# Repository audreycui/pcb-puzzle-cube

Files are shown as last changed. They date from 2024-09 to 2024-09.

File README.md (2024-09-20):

# pcb-puzzle-cube
Mechanical, Optical, &amp; Electronic Puzzle Cube

I made a puzzle cube for my wonderful electronics lab instructor who is also a professional trumpet player! A lot of the fun in making this was designing my circuits and mechanical components around 5 milled PCBs soldered together into a cube. Puzzles involve "playing" a sequence of notes on a flex PCB capacitive trumpet and using a butterfly flexure to align a laser path through a beamsplitter.

## Milled PCBs
From left to right, the sides of the cube include: 
1. WS2812b LEDs 
2. resistor combinations with pads for probing
3. laser diode regulated by a LM317 circuit and switched on/off electronically with a 2N7002 MOSFET 
4. QTPy ESP32 microcontroller
   
Sides 1 & 4 also include a photoresistor to detect laser beam alignment.

And the bottom:

5. 5V power jack, switches for the board power and laser power, mount for butterfly flexure
   


## Trumpet Capacitive Touch FlexPCB
I really wanted an excuse to fab a flexPCB, so I did so here. FlexPCB files are located in the <code>trumpet</code> subfolder. 

The connector end of the trumpet was designed to fit in a 6pin/1mm FPC connector. I ended up just soldering it directly to the board though, since I ended up finding an end mill small enough to carve out the 1mm pitch pads. It also helped me avoid buying an extra component. 



## Video Demo
Watch a video demo of the cube being solved [here](https://www.youtube.com/watch?v=AHTcb9tr4TA) :D

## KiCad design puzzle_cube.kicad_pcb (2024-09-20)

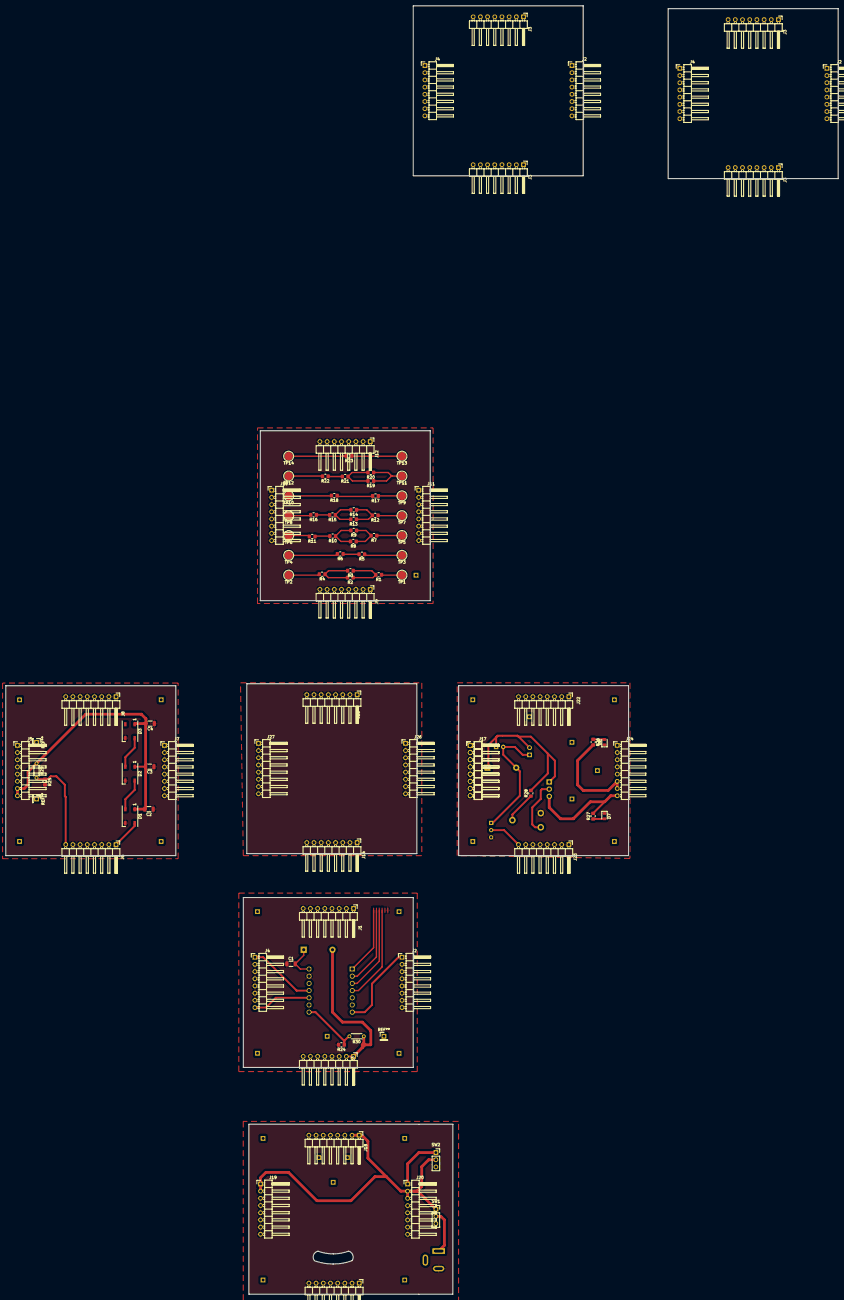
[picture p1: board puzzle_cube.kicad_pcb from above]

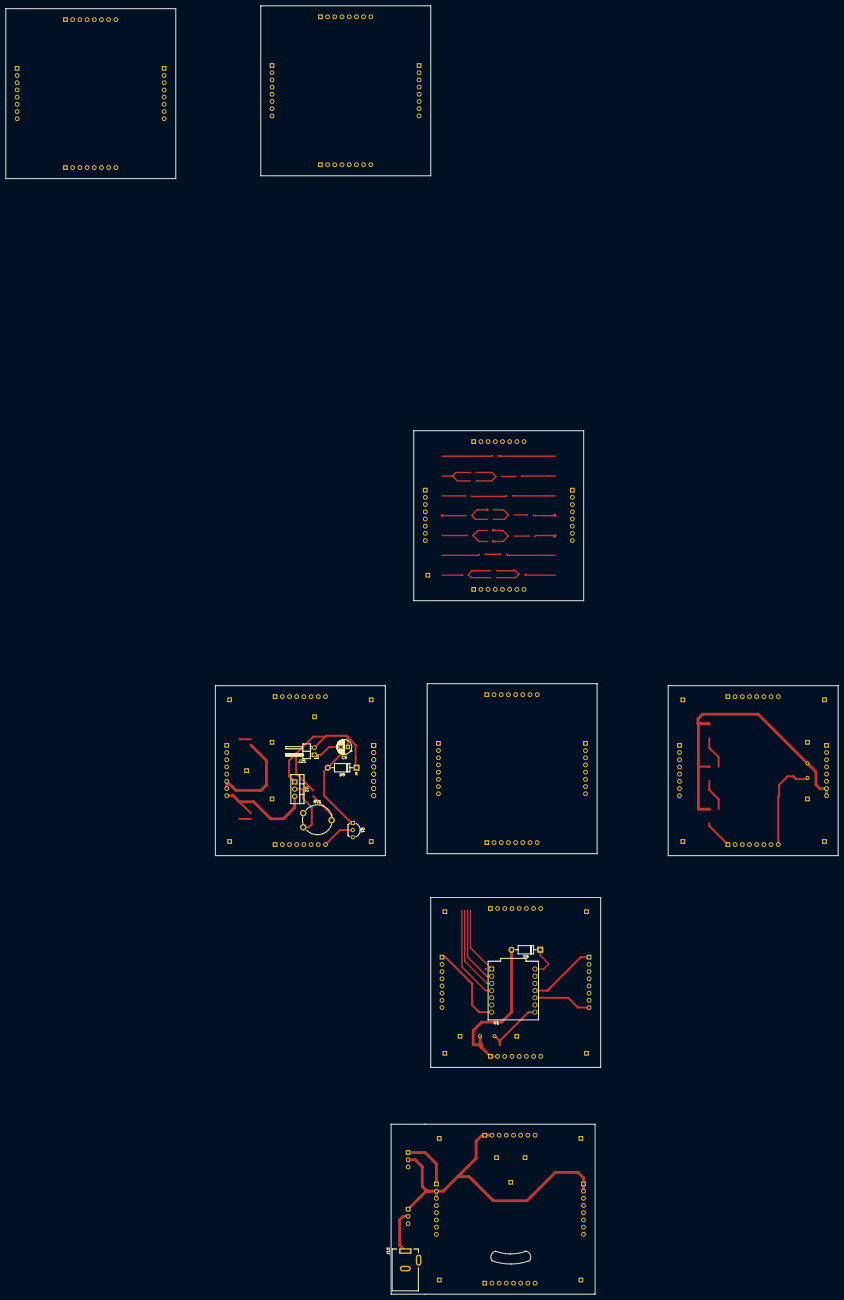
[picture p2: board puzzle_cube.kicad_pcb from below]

Board: 2 copper layers, 293.8 x 454.8 mm, 98 parts (9 on the bottom side), 47 nets.

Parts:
C1: C; C_1206_3216Metric
C2, C3, C4: 100uF; C_1206_3216Metric
C5: C; CP_Radial_D5.0mm_P2.50mm
D1, D2, D3: WS2812B; LED_WS2812B_PLCC4_5.0x5.0mm_P3.2mm
D6, D7: LED; LED_0805_2012Metric
D8, D9: 1N4007; D_DO-41_SOD81_P10.16mm_Horizontal
J1: qtpy2capacitive; PinHeader_1x08_P2.54mm_Horizontal
J2, J2#2, J3, J3#2, J3#4, J3#5, J4, J4#3: Conn_01x08_Pin; PinHeader_1x08_P2.54mm_Horizontal
J2#3: qtpy2laser; PinHeader_1x08_P2.54mm_Horizontal
J3#3: qtpy2beamsplitter; PinHeader_1x08_P2.54mm_Horizontal
J4#2: qtpy2leds; PinHeader_1x08_P2.54mm_Horizontal
J5: leds2beamsplitter; PinHeader_1x08_P2.54mm_Horizontal
J6: leds2qtpy; PinHeader_1x08_P2.54mm_Horizontal
J7: leds2capacitive; PinHeader_1x08_P2.54mm_Horizontal
J8: leds2resistors; PinHeader_1x08_P2.54mm_Horizontal
J9: resistors2capacitive; PinHeader_1x08_P2.54mm_Horizontal
J10: resistors2leds; PinHeader_1x08_P2.54mm_Horizontal
J11: resistors2laser; PinHeader_1x08_P2.54mm_Horizontal
J12: resistors2beamsplitter; PinHeader_1x08_P2.54mm_Horizontal
J13: trumpet_flexcable; 6pin_1.00pitch_FPC
J14: capacitive2qtpy; PinHeader_1x08_P2.54mm_Horizontal
J15: Barrel_Jack_MountingPin; BarrelJack_Kycon_KLDX-0202-xC_Horizontal
J17, J17#2: beamsplitter2resistors; PinHeader_1x08_P2.54mm_Horizontal
J18: beamsplitter2qtpy; PinHeader_1x08_P2.54mm_Horizontal
J19: beamsplitter2leds; PinHeader_1x08_P2.54mm_Horizontal
J20: beamsplitter2laser; PinHeader_1x08_P2.54mm_Horizontal
J21: laser2capacitve; PinHeader_1x08_P2.54mm_Horizontal
J22: laser2resistors; PinHeader_1x08_P2.54mm_Horizontal
J23: laser2qtpy; PinHeader_1x08_P2.54mm_Horizontal
J24: laser2beamsplitter; PinHeader_1x08_P2.54mm_Horizontal
J25: laser connector; PinHeader_1x02_P2.54mm_Horizontal
J26: capacitive2laser; PinHeader_1x08_P2.54mm_Horizontal
J27: capacitive2led; PinHeader_1x08_P2.54mm_Horizontal
J28: capacitive2resistor; PinHeader_1x08_P2.54mm_Horizontal
Q1: NPN; TO-92L_Inline_Wide
R1: 200; R_0805_2012Metric_Pad1.20x1.40mm_HandSolder
R2, R3: 120; R_0805_2012Metric_Pad1.20x1.40mm_HandSolder
R4: 62; R_0805_2012Metric_Pad1.20x1.40mm_HandSolder
R5, R7, R12, R17: 430; R_0805_2012Metric_Pad1.20x1.40mm_HandSolder
R6, R10, R15, R18: 10; R_0805_2012Metric_Pad1.20x1.40mm_HandSolder
R8, R9, R13, R14: 68; R_0805_2012Metric_Pad1.20x1.40mm_HandSolder
R11, R16: 20; R_0805_2012Metric_Pad1.20x1.40mm_HandSolder
R19, R20: 680; R_0805_2012Metric_Pad1.20x1.40mm_HandSolder
R21: 51; R_0805_2012Metric_Pad1.20x1.40mm_HandSolder
R22: 1; R_0805_2012Metric_Pad1.20x1.40mm_HandSolder
R23: 330; R_0805_2012Metric_Pad1.20x1.40mm_HandSolder
R24, R25: 10k; R_0805_2012Metric_Pad1.20x1.40mm_HandSolder
R26, R27: 1k; R_0805_2012Metric_Pad1.20x1.40mm_HandSolder
R28: R_US; R_0805_2012Metric_Pad1.20x1.40mm_HandSolder
R29, R30: R_Photo; R_Axial_DIN0204_L3.6mm_D1.6mm_P5.08mm_Horizontal
RV1: R_Potentiometer_Trim_US; Potentiometer_Piher_PT-10-V10_Vertical
SW1: power; PinSocket_1x03_P2.54mm_Vertical
SW2: laser; PinSocket_1x03_P2.54mm_Vertical
TP1, TP2, TP3, TP4, TP5, TP6, TP7, TP8, TP9, TP10, TP11, TP12, TP13, TP14: TestPoint; TestPoint_Pad_D3.0mm
U1: ADAFRUIT_QT_PY; MODULE_ADAFRUIT_QT_PY
U2: LM317L_TO92; TO-220-3_Vertical

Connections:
+5V: C2.2, C3.2, C4.2, D1.1 (VDD), D2.1 (VDD), D3.1 (VDD), D9.2 (A), J3#3.1, J3#3.2, J5.7, J5.8, J18.1, J18.2, J19.1, J19.2, J20.2, J20.3, J24.6, J24.7, R26.2, R29.1, R30.1, SW1.1 (A), SW2.2 (B)
/beamsplitter/5V_beforeswitch: J15.1, SW1.2 (B)
/beamsplitter/laser_power: J20.1, J24.8, R27.2, SW2.1 (A), U2.3 (VI)
/laser/laser_base: J2#3.1, J23.8, Q1.2 (B), U1.7 (A6/D6/TX)
/leds_detector/D1: D1.2 (DOUT), D2.4 (DIN)
/leds_detector/D2: D2.2 (DOUT), D3.4 (DIN)
/leds_detector/detector_2: J4#2.8, J6.8, R25.1, R29.2, U1.10 (A9/D9/MISO)
/leds_detector/leds: D1.4 (DIN), J4#2.1, J6.1, U1.11 (A10/D10/MOSI)
/qtpy/detector_1: R24.1, R30.2, U1.8 (A7/D7/RX)
/qtpy/enter: J13.1, U1.1 (A0/D0/DAC)
/qtpy/trumpet_1: J13.2, U1.2 (A1/D1)
/qtpy/trumpet_2: J13.3, U1.3 (A2/D2)
/qtpy/trumpet_3: J13.4, U1.4 (A3/D3)
GND: C1.1, C2.1, C3.1, C4.1, D1.3 (VSS), D2.3 (VSS), D3.3 (VSS), D6.1 (K), D7.1 (K), J1.1, J1.2, J1.3, J1.4, J1.5, J1.6, J1.7, J1.8, J2#3.2, J2#3.3, J2#3.4, J2#3.5, J2#3.6, J2#3.7, J2#3.8, J3#3.3, J3#3.4, J3#3.5, J3#3.6, J3#3.7, J3#3.8, J4#2.2, J4#2.3, J4#2.4, J4#2.5, J4#2.6, J4#2.7, J5.1, J5.2, J5.3, J5.4, J5.5, J5.6, J6.2, J6.3, J6.4, J6.5, J6.6, J6.7, J7.1, J7.2, J7.3, J7.4, J7.5, J7.6, J7.7, J7.8, J8.1, J8.2, J8.3, J8.4, J8.5, J8.6, J8.7, J8.8, J9.1, J9.2, J9.3, J9.4, J9.5, J9.6, J9.7, J9.8, J10.1, J10.2, J10.3, J10.4, J10.5, J10.6, J10.7, J10.8, J11.1, J11.2, J11.3, J11.4, J11.5, J11.6, J11.7, J11.8, J12.1, J12.2, J12.3, J12.4, J12.5, J12.6, J12.7, J12.8, J13.5, J13.6, J14.1, J14.2, J14.3, J14.4, J14.5, J14.6, J14.7, J14.8, J15.2, J17.1, J17.2, J17.3, J17.4, J17.5, J17.6, J17.7, J17.8, J17#2.1, J17#2.2, J17#2.3, J17#2.4, J17#2.5, J17#2.6, J17#2.7, J17#2.8, J18.3, J18.4, J18.5, J18.6, J18.7, J18.8, J19.3, J19.4, J19.5, J19.6, J19.7, J19.8, J20.4, J20.5, J20.6, J20.7, J20.8, J21.1, J21.2, J21.3, J21.4, J21.5, J21.6, J21.7, J21.8, J22.1, J22.2, J22.3, J22.4, J22.5, J22.6, J22.7, J22.8, J23.1, J23.2, J23.3, J23.4, J23.5, J23.6, J23.7, J24.1, J24.2, J24.3, J24.4, J24.5, J26.1, J26.2, J26.3, J26.4, J26.5, J26.6, J26.7, J26.8, J27.1, J27.2, J27.3, J27.4, J27.5, J27.6, J27.7, J27.8, J28.1, J28.2, J28.3, J28.4, J28.5, J28.6, J28.7, J28.8, Q1.3 (E), R24.2, R25.2, RV1.3, U1.13 (GND)
unnamed: D6.2 (A), R26.1
unnamed: D7.2 (A), R27.1
unnamed: C5.2, D8.2 (A), J25.1, Q1.1 (C)
unnamed: C5.1, D8.1 (K), J25.2, R28.2, U2.1 (ADJ)
unnamed: C1.2, D9.1 (K), U1.14 (5V)
unnamed: R1.1, TP1.1
unnamed: R1.2, R2.1, R3.1
unnamed: R2.2, R3.2, R4.1
unnamed: R4.2, TP2.1
unnamed: R5.1, TP3.1
unnamed: R5.2, R6.1
unnamed: R6.2, TP4.1
unnamed: R7.1, TP5.1
unnamed: R7.2, R8.1, R9.1
unnamed: R8.2, R9.2, R10.1
unnamed: R10.2, R11.1
unnamed: R11.2, TP6.1
unnamed: R12.1, TP7.1
unnamed: R12.2, R13.1, R14.1
unnamed: R13.2, R14.2, R15.1
unnamed: R15.2, R16.1
unnamed: R16.2, TP8.1
unnamed: R17.1, TP9.1
unnamed: R17.2, R18.1
unnamed: R18.2, TP10.1
unnamed: R19.1, R20.1, TP11.1
unnamed: R19.2, R20.2, R21.1
unnamed: R21.2, R22.1
unnamed: R22.2, TP12.1
unnamed: R23.1, TP13.1
unnamed: R23.2, TP14.1
unnamed: R28.1, RV1.2
unnamed: RV1.1, U2.2 (VO)
